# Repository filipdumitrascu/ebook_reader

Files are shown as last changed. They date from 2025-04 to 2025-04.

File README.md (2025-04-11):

# Ebook Reader (OpenBook Project)

## Contributor: Dumitrașcu Filip-Teodor 333CA

## 1. Diagrama bloc

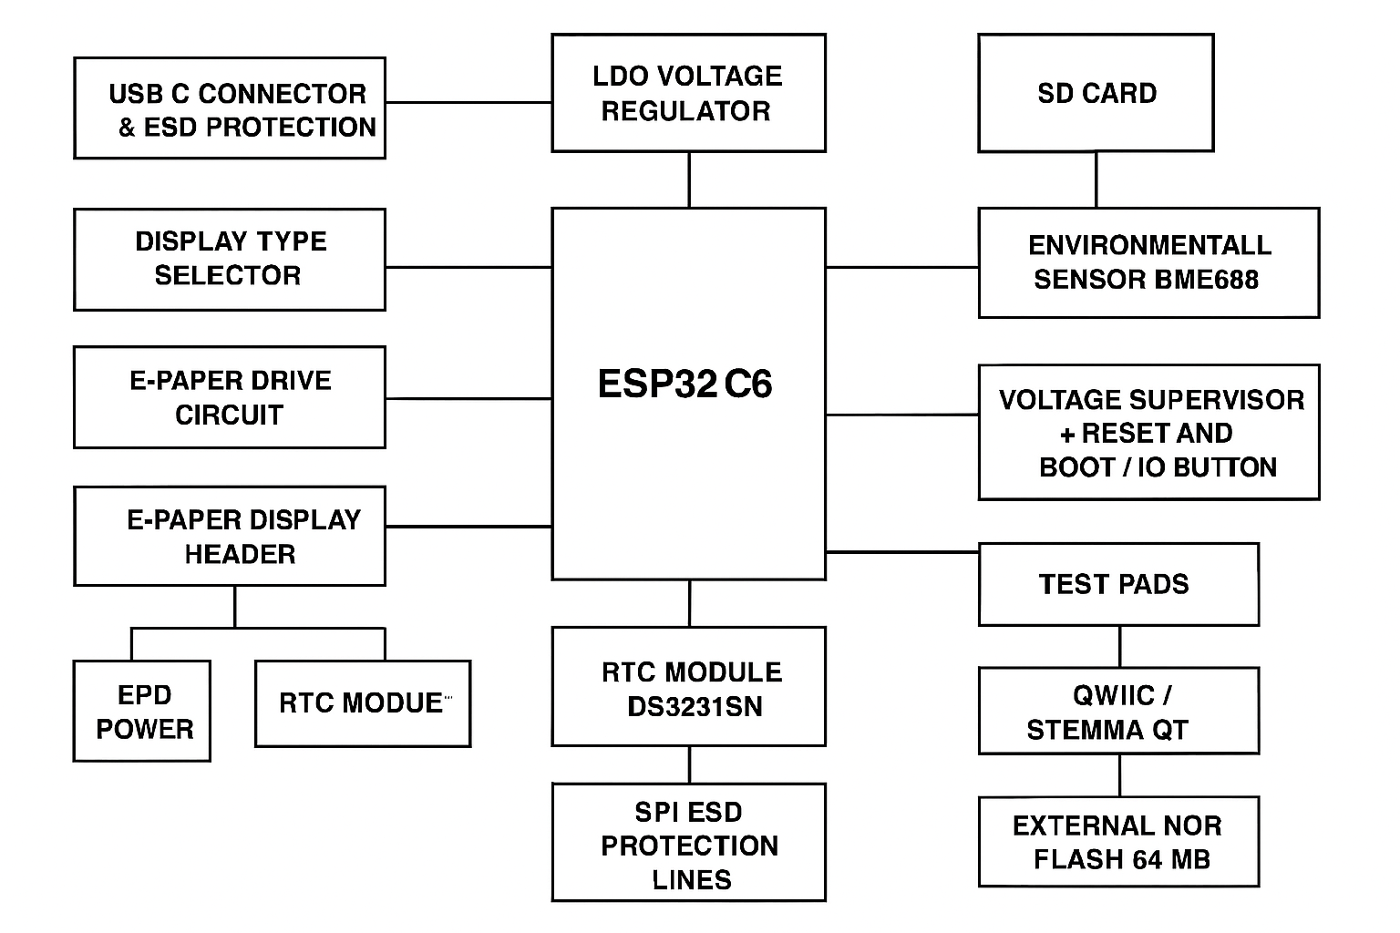
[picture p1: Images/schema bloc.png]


## 2. Bill Of Materials (BOM)

| Nume | Componenta | Link de achizitie | Datasheet |
|---|---|---|---|
| PFMF.050.1 | VARISTORCN1812 | [Component Search Engine](https://componentsearchengine.com/part-view/VE1812K401R050/KEMET) | [Datasheet](https://content.kemet.com/datasheets/KEM_V0003_VE.pdf) |
| Rezistente | RR0402 | [Component Search Engine](https://componentsearchengine.com/part-view/R0402%201%25%20100%20K%20(RC0402FR-07100KL)/YAGEO) | [Datasheet](https://content.kemet.com/datasheets/KEM_V0003_VE.pdf)
| J2 | SAMACSYS_PARTS_USB4110-GF-A | [Component Search Engine](https://componentsearchengine.com/part-view/USB4110-GF-A/GCT%20(GLOBAL%20CONNECTOR%20TECHNOLOGY)) | [Datasheet](https://gct.co/files/drawings/usb4110.pdf) |
| D1 | USBLC6-2SC6Y | [Snapeda](https://www.snapeda.com/parts/USBLC6-2SC6Y/STMicroelectronics/view-part/?ref=eda) | [Datasheet](https://www.snapeda.com/parts/USBLC6-2SC6Y/STMicroelectronics/datasheet/) |
| Condensatoare | CC0402 | [Component Search Engine](https://componentsearchengine.com/part-view/CC0402MRX5R5BB106/YAGEO) | [Datasheet](https://componentsearchengine.com/Datasheets/2/CC0402MRX5R5BB106.pdf)|
| Q1 | WROVER_SPARKFUN-DISCRETESEMI_MOSFET_PCH-DMG2305UX-7 | [Component Search Engine](https://componentsearchengine.com/part-view/DMG2305UX-7/Diodes%20Incorporated) | [Datasheet](https://www.diodes.com//assets/Datasheets/DMG2305UX.pdf) |
| D2 | WROVER_AVX---SD0805S020S1R0_AVX_SD0805S020S1R0_0_0AVX_SD0805S020S1R0_0_0 | [Mouser](https://eu.mouser.com/ProductDetail/KYOCERA-AVX/SD0805S020S1R0?qs=jCA%252BPfw4LHbpkAoSnwrdjw%3D%3D) | [Datasheet](https://eu.mouser.com/datasheet/2/40/schottky-3165252.pdf) |
| C3 | RCL_CPOL-EUCT3528 | [Snapeda](https://eu.mouser.com/ProductDetail/KYOCERA-AVX/F910J107MBAAJ6?qs=PqoDHHvF649LraCA%2FjeGXg%3D%3D) | [Datasheet](https://s3.amazonaws.com/snapeda/datasheet/TAJB475K025RNJ_AVX.pdf) |
| J4 | 112A-TAAR-R03_ATTEND | [Snapeda](https://www.snapeda.com/parts/112A-TAAR-R03/Attend/view-part/) | [Datasheet](https://www.snapeda.com/parts/112A-TAAR-R03/Attend/datasheet/) |
| U2 | C6-WROOM-1-N8 | [Snapeda](https://www.snapeda.com/parts/ESP32-C6-WROOM-1-N8/Espressif+Systems/view-part/?ref=eda) | [Datasheet](https://www.snapeda.com/parts/ESP32-C6-WROOM-1-N8/Espressif%20Systems/datasheet/) |
| MCP73831 | WROVER_SPARKFUN-IC-POWER_MCP73831 | [Mouser](https://eu.mouser.com/ProductDetail/Microchip-Technology/MCP73831T-2ACI-OT?qs=yUQqVecv4qvbBQBGbHx0Mw%3D%3D) | [Datasheet](https://eu.mouser.com/datasheet/2/268/MCP73831_Family_Data_Sheet_DS20001984H-3441711.pdf) |
| CHG_LED | ADAFRUIT_LEDCHIP-LED0603 | [Snapeda](https://www.snapeda.com/parts/KP-1608SURCK/Kingbright/view-part/?ref=search&t=LED%200603) | [Datasheet](https://www.snapeda.com/parts/KP-1608SURCK/Kingbright/datasheet/) |
| L1 | 744043680IND_4828-WE-TPC_WRE | [Mouser](https://eu.mouser.com/ProductDetail/Wurth-Elektronik/744043680?qs=PGXP4M47uW6VkZq%252BkzjrHA%3D%3D) | [Datasheet](https://www.we-online.com/components/products/datasheet/744043680.pdf) |
| D3 | MBR0530 | [Snapeda](https://www.snapeda.com/parts/MBR0530/Onsemi/view-part/?ref=eda) | [Datasheet](https://www.snapeda.com/parts/MBR0530/ON%20Semiconductor/datasheet/) |
| Q3 | SI1308EDL-T1-GE3 | [Snapeda](https://www.snapeda.com/parts/SI1308EDL-T1-GE3/Vishay+Siliconix/view-part/?ref=eda) | [Datasheet](https://www.snapeda.com/parts/SI1308EDL-T1-GE3/Vishay+Siliconix/view-part/?ref=eda) |
| SJ1 | SJ | [GrabCad](https://grabcad.com/library/solder-jumpers-1) | [Datasheet](https://www.we-online.com/components/products/datasheet/609002115121.pdf) |
| J1 | FH34SRJ-24S-0.5SH_99_ | [Component Search Engine](https://componentsearchengine.com/part-view/FH34SRJ-24S-0.5SH(99)/Hirose) | [Datasheet](https://www.hirose.com/en/product/document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) |
| Sensor2  | WROVER_BME680_BME680 | [Snapeda](https://www.snapeda.com/parts/BME680/Bosch/view-part/?welcome=home) | [Datasheet](https://www.snapeda.com/parts/BME680/Bosch%20Sensortec/datasheet/) |
| Buttons | BUTTON_CUSYOMV1 | [Snapeda](https://www.snapeda.com/parts/EVQP7L01P/Panasonic/view-part/?ref=dk&t=evqp7l01p&con_ref=None) | [Datasheet](https://s3.amazonaws.com/snapeda/datasheet/EVQP7L01P_Panasonic.pdf) |
| U4 | MAX17048G+T10 | [Snapeda](https://www.snapeda.com/parts/MAX17048G+T10/Analog+Devices/view-part/?ref=eda) | [Datasheet](https://www.snapeda.com/parts/MAX17048G+T10/Analog%20Devices/datasheet/) |
| U3 | DS3231SN# | [Snapeda](https://www.snapeda.com/parts/RV-3029-C3-TB-QA-OPT.B/Micro%20Crystal/view-part/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) | [Datasheet](https://www.snapeda.com/parts/DS3231SN%23/Analog%20Devices/datasheet/) |
| C10_SUPERCAP | CPH3225A | [Snapeda](https://www.snapeda.com/parts/CPH3225A/Seiko+Instruments/view-part/?ref=eda) | [Datasheet](https://www.snapeda.com/parts/CPH3225A/Seiko%20Instruments/datasheet/) |
| J3 | QWIIC_CONNECTORJS-1MM | [Snapeda](https://www.snapeda.com/parts/PRT-14417/SparkFun%20Electronics/view-part/?ref=search&t=QWIIC_CONNECTORJS-1MM) | [Datasheet](https://www.snapeda.com/parts/PRT-14417/SparkFun%20Electronics/view-part/?ref=search&t=QWIIC_CONNECTORJS-1MM) |
| D6,8,9,10,11,12 | PGB1010603MR | [Snapeda](https://www.snapeda.com/parts/PGB1010603MR/Littelfuse/view-part/?ref=eda) | [Datasheet](https://www.snapeda.com/parts/PGB1010603MR/Littelfuse%20Inc./datasheet/) |
| U1 | W25Q512JVEIQ | [Snapeda](https://www.snapeda.com/parts/W25Q512JVEIQ/Winbond+Electronics/view-part/?ref=eda) | [Datasheet](https://www.snapeda.com/parts/W25Q512JVEIQ/Winbond%20Electronics/datasheet/) |

## 3. Descrierea functionalitatii hardware

### Componente si interfete
- **ESP32-C6-WROOM-1-N8** este microcontrolerul principal, responsabil cu gestionarea intregului sistem, comunicarea cu senzorii si modulele externe, dar si cu managementul alimentarii.
  - Arhitectura: 32-bit RISC-V
  - Frecventa de lucru: 160 MHz
  - Conectivitate wireless: Wi-Fi 6 (2.4 GHz), Bluetooth 5.0

- **Bateria Li-Po** de 3.7V, 1800mAh asigura alimentarea sistemului in mod portabil.
- **Circuitul de incarcare** bazat pe MCP73831T gestioneaza incarcarea sigura a bateriei.
- **Regulatorul LDO** stabilizeaza tensiunea de alimentare la 3.3V pentru toate componentele.

- **Display-ul E-Ink** de 7.5 inch permite afisarea informatiilor cu un consum minim de energie.
  - Rezolutie: 800x480 pixeli
  - Interfata comunicatie: SPI

- **Modulul SD Card** permite stocarea datelor pe un card MicroSD (FAT32).
  - Interfata comunicatie: SPI

- **Memoria NOR Flash externa** ofera 64MB pentru stocare suplimentara.
  - Interfata comunicatie: SPI

- **Senzorul ambiental BME688** masoara temperatura, umiditatea, presiunea si nivelul gazelor.
  - Interfata comunicatie: I2C

- **Modulul RTC DS3231SN** mentine ora si data chiar si cand sistemul este oprit.
  - Interfata comunicatie: I2C

### Conexiuni si specificatii
- **Conectorul USB-C** permite alimentarea sistemului si transferul de date.
  - Protectie integrata ESD si dioda Schottky pentru protectie la polaritate inversa.

- **Butoane tactile** utilizate pentru interactiunea utilizatorului.

- **Interfete de comunicatie** folosite:
  - GPIO: pentru butoane si operatii I/O generale.
  - SPI: pentru SD Card, memoria NOR Flash si ecranul E-Ink.
  - I2C: pentru senzorul BME688 si modulul RTC.
  - UART: pentru debugging si comunicatie seriala.
  - Wi-Fi & Bluetooth: oferite de ESP32-C6 pentru conectivitate wireless.

## 4.Estimare Consum de Putere

| Componenta | Consum Curent (mA) | Tensiune (V) | Putere (mW) |
|---|---|---|---|
| ESP32-C6 (Wi-Fi activ) | 200 | 3.3 | 660 |
| Ecran E-Paper (Actualizare)| 40 | 3.3 | 132 |
| Senzor BME688 (Măsurare) | 3.1 | 3.3 | 10.23 |
| Modul RTC (Activ) | 0.15 | 3.3 | 0.495 |
| Card SD (Activ) | 50 | 3.3 | 165 |
| Memorie NOR Flash externa  | 25 | 3.3 | 82.5 |

### Consum Total Estimat
- Curent Total: ~318.5 mA  
- Tensiune Alimentare: 3.3 V  
- Putere Totala: 1050.72 mW

## 5. Pini utilizati pe ESP32-C6

| Pin ESP32-C6 | Funcționalitate | Componentă conectată |
|---|---|---|
| 3 | EPD_BUSY | Semnal de stare pentru EPD (E-paper display) |
| 4 | SS_SD | Chip Select pentru card SD |
| 5 | EPD_DC | Pin Data/Command pentru EPD |
| 6 | SCK | Linie de ceas SPI comună pentru EPD, SD Card și memorie externa |
| 7 | MOSI | Linie MOSI SPI (Master Out Slave In) comuna pentru EPD, SD Card si memorie externa |
| 2 | MISO | Linie MISO SPI (Master In Slave Out) comuna pentru SD Card si memorie externa |
| 10 | CS_EPD | Chip Select pentru EPD |
| 11 | CS_FLASH | Chip Select pentru memorie externă NOR Flash |
| 23 | EPD_RST | Reset pentru EPD |
| 21 | SDA | Linie de date I2C comună pentru BME688, DS3231 si monitorizare baterie |
| 22 | SCL | Linie de ceas I2C comună pentru BME688, DS3231 si monitorizare baterie |
| 18 | RTC_RST | Reset pentru modulul RTC (DS3231) |
| 1 | 32KHZ | Oscilator 32 kHz pentru RTC |
| 0 | INT_RTC | Semnal de intrerupere de la RTC |
| 9 | BOOT | Buton pentru boot/flash (input utilizator) |
| 15 | CHANGE | Buton pentru schimbare stare/functii (input utilizator) |
| EN | RESET | Buton/reset general pentru sistem |
| - | USB-C | Alimentare si programare prin USB-C (cu protecție ESD și dioda Schottky) |

## 6. Aspecte de design si probleme intampinate

- **Schematic**: Componentele au fost pozitionate conform specificatiilor arhitectului de sistem. (am pus inclusiv frame cu nume). Am acceptat 15 warninguri la verificarea erc
- **PCB 2D**: Am dat split sa obtin forma dorita in specificatii si am plasat componentele pe margini cu masurile primite pentru a ma asigura ca varianta 3d intra in carcasa si mufele sunt aliniate. Am pozitionat si componentele centrale ca in poza din specificatii. Am autorutat mai intai neturile power cu width de 0.3 mm fara trecere prin plan bottom si pe urma neturile neturile normale de 0.15 cu trecere prin plan bottom. Am pus via stitching langa modulul esp si planurile de masa atat pe top cat si pe bottom . Intradevar, sunt foarte multe viasuri puse. Poate o strategie mai buna ar fi fost sa rutez mai intai neturile normale ca sa nu fie spatiu ocupat si sa puna cat mai putine viasuri. Alta varianta ar fi fost sa rutez tot manual. (cam hardcore pentru primul proiect in fusion 360 cu acest dispozitiv un ebook reader destul de complex). Am modificat footprintul pentru piese in care intrau neturi de 0.3 mm fiind mai late decat suporta pinul piesei. In verificarea drc am 2 erori aprobate despre gauri in footprintul unei componente. (greseala a arhitectului de sistem)
- **PCB 3D**: Am downloadat step fielul si uploadat pentru fiecare componenta astfel incat sa aiba reprezentare in 3d. Test padurile sunt facute custom. Am plasat pcbul in carcasa primita de la arhitectul de sistem. Tin sa precizez ca dimensiunea de 15.30mm fata de coltul stanga sus (cu originea in coltul stanga jos) plaseaza sd cardu mai jos fata de gaura data in carcasa. Am ales sa mut gaura carcasei pentru a rezolva problema (decat sa schimb rute, replasez sd carsd si alte pushuri spre 3d)
- **Baterie, display**: Am facut o baterie si un ecram custom (am mai invatat fusion decat sa le iau step fileul de pe net) cu precizarea ca lipsesc firele de conexiune (cam mult pentru un prim proiect fusion). Dimensiuniile si componentele lor sunt luate din datasheeturile aferente.
- **Bom, PcP** Am generat de la manufacturing bom, pick and place si gerbers aferente pcbului.

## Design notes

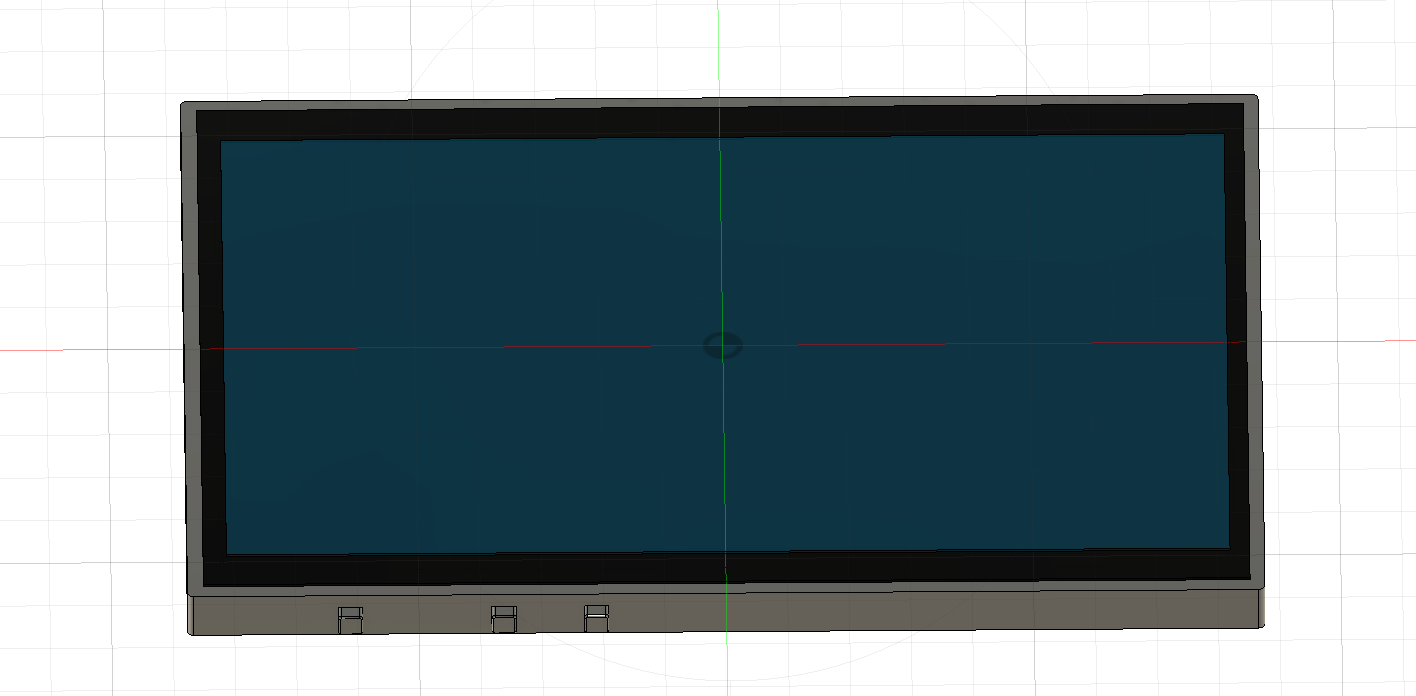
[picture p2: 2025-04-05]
Images/openbook enclosure front.png

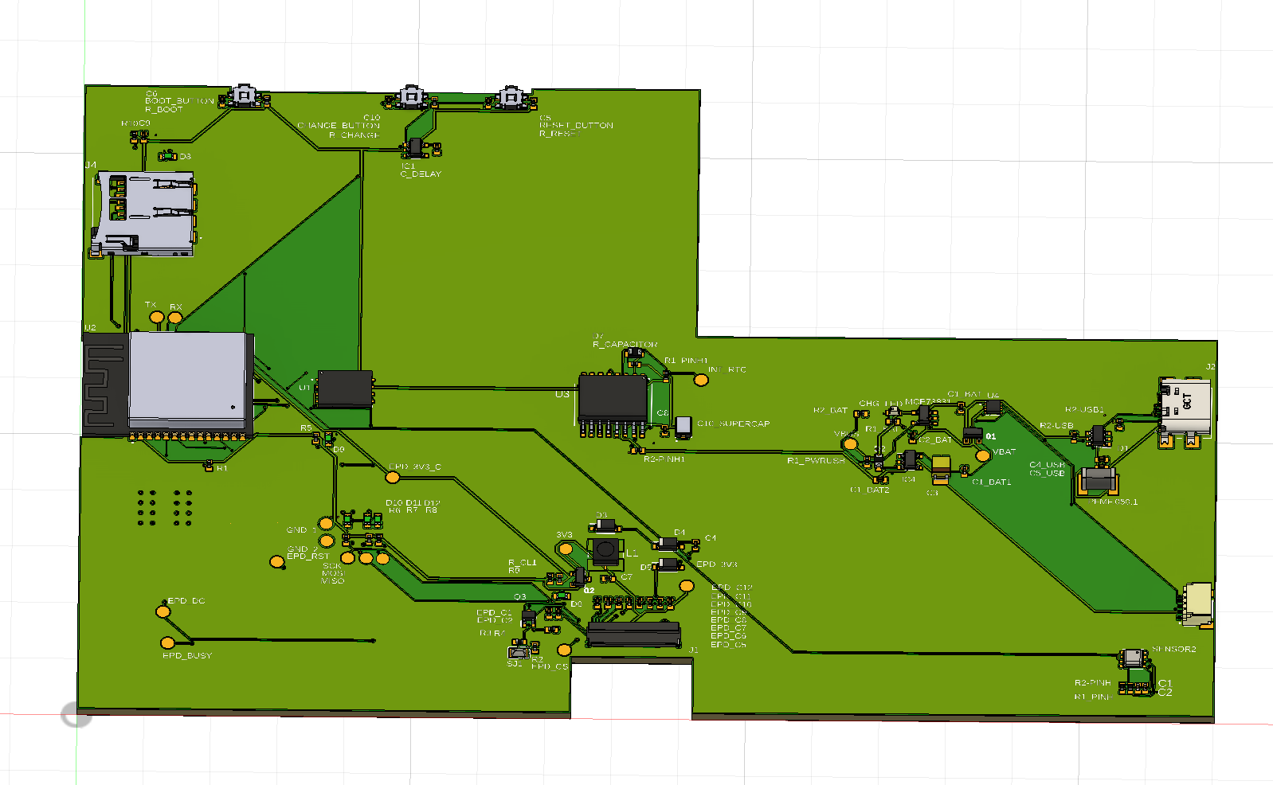
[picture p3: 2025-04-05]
Images/pcb front.png

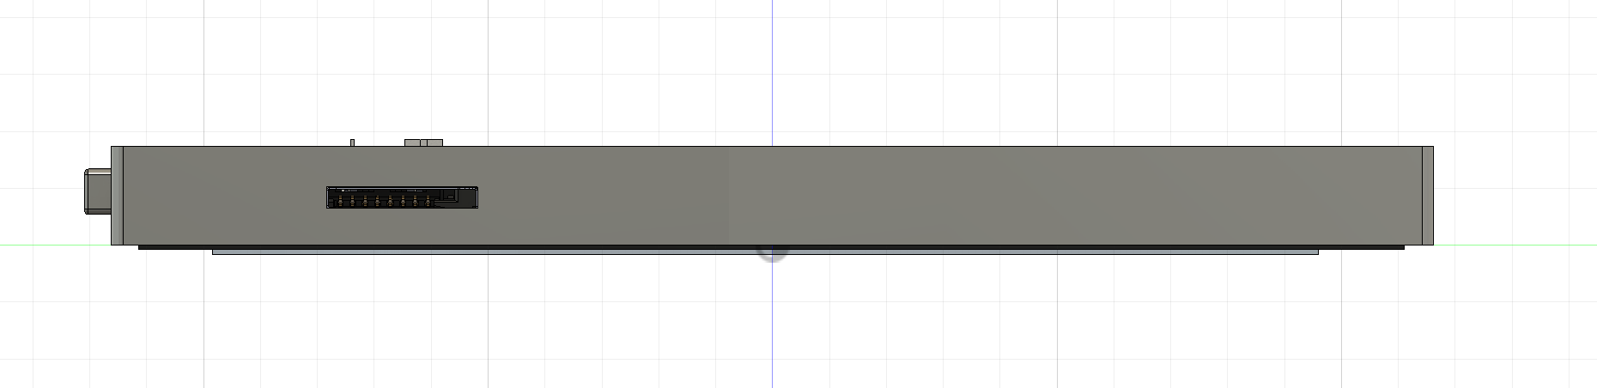
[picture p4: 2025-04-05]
Images/openbook enclosure top.png

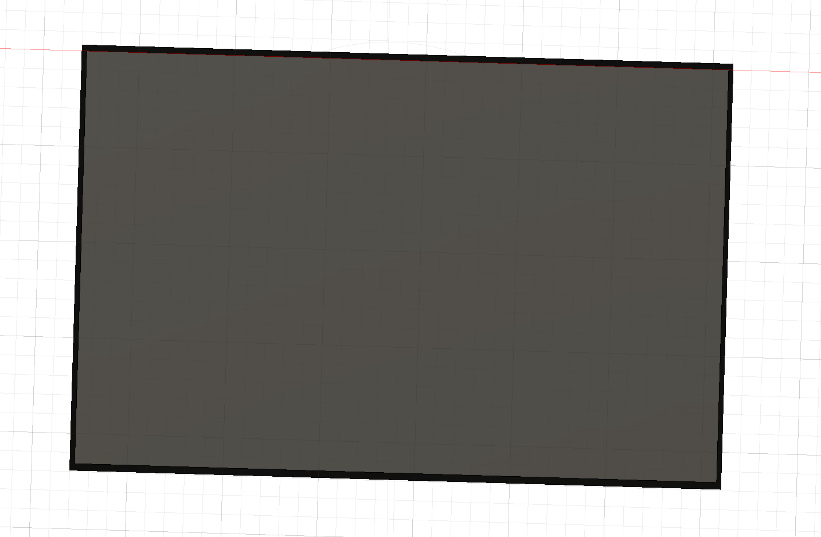
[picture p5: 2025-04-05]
Images/display back.png

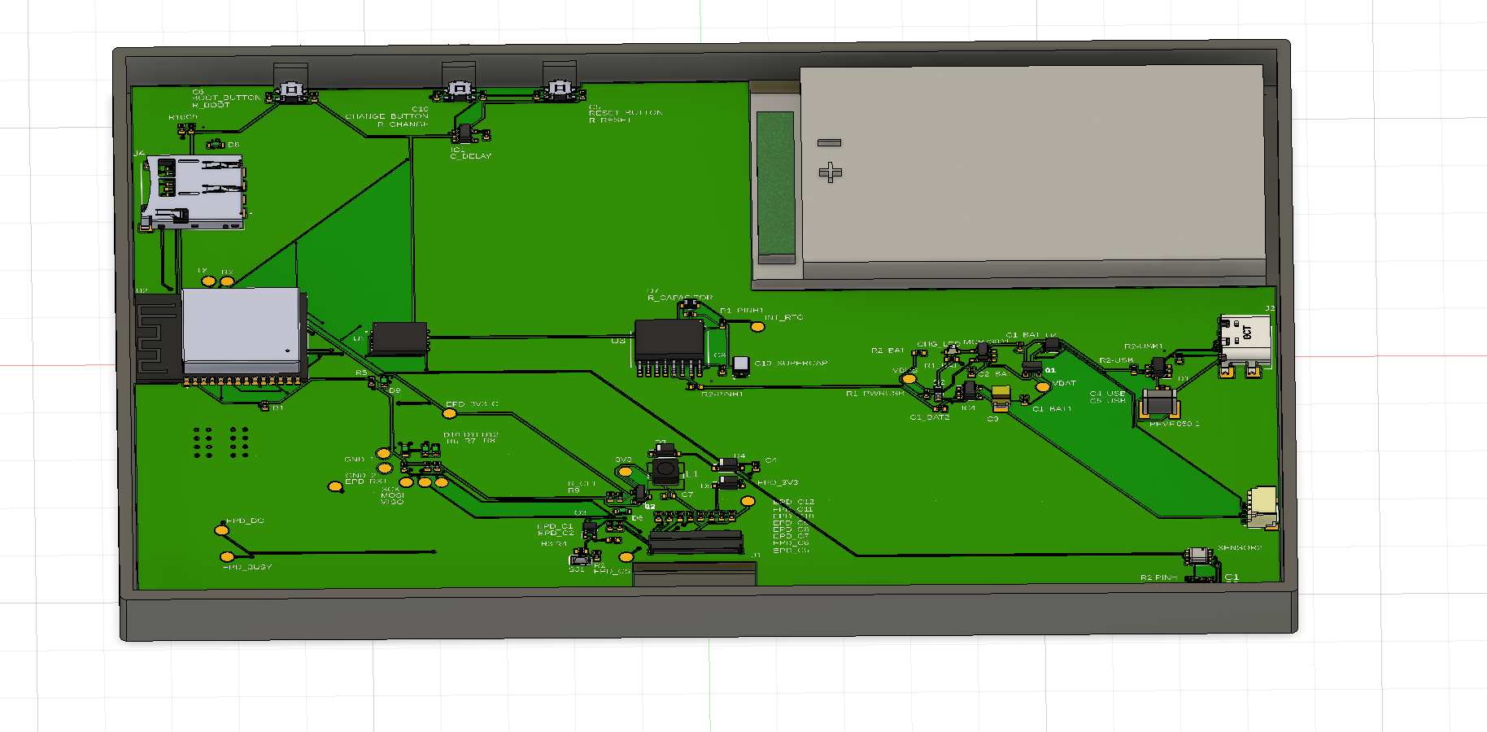
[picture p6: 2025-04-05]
Images/openbook enclosure inside.png

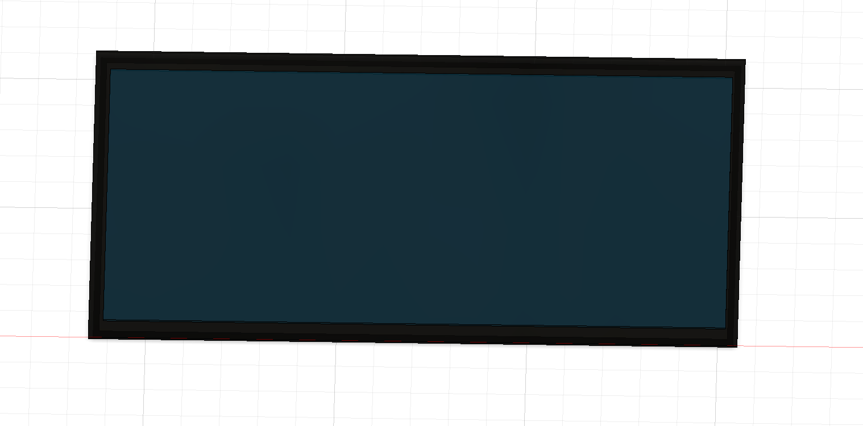
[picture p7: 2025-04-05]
Images/display front.png

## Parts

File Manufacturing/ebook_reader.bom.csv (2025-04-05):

Qty | Value | Device | Package | Parts | Description | ARROW_PART_NUMBER | ARROW_PRICE-STOCK | AVAILABILITY | CENTROID_NOT_SPECIFIED | CHECK_PRICES | COPYRIGHT | DATASHEET | DESCRIPTION | DIGIKEY_DESCRIPTION | DIGIKEY_PART_NUMBER | HEIGHT | LEAD_FREE | MANUFACTURER_NAME | MANUFACTURER_PART_NUMBER | MF | MFR_NAME | MOUSER_PART_NUMBER | MOUSER_PRICE-STOCK | MOUSER_TESTING_PART_NUMBER | MOUSER_TESTING_PRICE-STOCK | MP | MPN | PACKAGE | POPULARITY | PREFIX | PRICE | PROD_ID | PURCHASE-URL | ROHS | SNAPEDA_LINK | SPICEMODEL | SPICEPREFIX | TEMPERATURE_RANGE_HIGH | TEMPERATURE_RANGE_LOW | TP_SIGNAL_NAME | VALUE
1 |  | ADAFRUIT_LEDCHIP-LED0603 | ADAFRUIT_CHIP-LED0603 | CHG_LED | LED |  |  |  |  | https://www.snapeda.com/parts/KP-1608SURCK/Kingbright/view-part/?ref=search&t=LED%200603
1 |  | SJ | SJ | SJ1 | SMD solder JUMPER |  |  |  |  | https://grabcad.com/library/solder-jumpers-1 |  |  |  |  |  |  |  |  |  |  |  |  |  |  |  |  |  |  | 3
1 | 0.47 | ESP32_WROVER_EAGLE-LTSPICE_RR0402 | ESP32_WROVER_EAGLE-LTSPICE_R0402 | R3 | RESISTOR, European symbol |  |  |  |  | https://componentsearchengine.com/part-view/R0402%201%25%20100%20K%20(RC0402FR-07100KL)/YAGEO |  |  |  |  |  |  |  |  |  |  |  |  |  |  |  |  |  |  |  |  |  |  |  |  |  | NONE | R
1 | 10 uF | ESP32_WROVER_EAGLE-LTSPICE_CC0402 | ESP32_WROVER_EAGLE-LTSPICE_C0402 | C7 | CAPACITOR, European symbol |  |  |  |  | https://componentsearchengine.com/part-view/CC0402MRX5R5BB106/YAGEO |  |  |  |  |  |  |  |  |  |  |  |  |  |  |  |  |  |  |  |  |  |  |  |  |  | NONE | C
1 | 100 nF | ESP32_WROVER_EAGLE-LTSPICE_CC0402 | ESP32_WROVER_EAGLE-LTSPICE_C0402 | C9 | CAPACITOR, European symbol |  |  |  |  |  |  |  |  |  |  |  |  |  |  |  |  |  |  |  |  |  |  |  |  |  |  |  |  |  |  | NONE | C
1 | 100k | ESP32_WROVER_EAGLE-LTSPICE_RR0402 | ESP32_WROVER_EAGLE-LTSPICE_R0402 | R1_PWRUSB | RESISTOR, European symbol |  |  |  |  |  |  |  |  |  |  |  |  |  |  |  |  |  |  |  |  |  |  |  |  |  |  |  |  |  |  | NONE | R
7 | 100nF | ESP32_WROVER_EAGLE-LTSPICE_CC0402 | ESP32_WROVER_EAGLE-LTSPICE_C0402 | C1, C2, C4_USB, C6, C8, C10, C_DELAY | CAPACITOR, European symbol |  |  |  |  |  |  |  |  |  |  |  |  |  |  |  |  |  |  |  |  |  |  |  |  |  |  |  |  |  |  | NONE | C
1 | 100uF TANT | RCL_CPOL-EUCT3528 | RCL_CT3528 | C3 | POLARIZED CAPACITOR, European symbol |  |  |  |  | https://eu.mouser.com/ProductDetail/KYOCERA-AVX/F910J107MBAAJ6?qs=PqoDHHvF649LraCA%2FjeGXg%3D%3D |  |  |  |  |  |  |  |  |  |  |  |  |  |  |  |  |  |  | 0 |  |  |  |  |  |  |  | C
16 | 10k | ESP32_WROVER_EAGLE-LTSPICE_RR0402 | ESP32_WROVER_EAGLE-LTSPICE_R0402 | R1, R1_PINH, R1_PINH1, R2-PINH, R2-PINH1, R4, R5, R6, R7, R8, R9, R10, R_BOOT, R_CHANGE, R_CL1, R_RESET | RESISTOR, European symbol |  |  |  |  |  |  |  |  |  |  |  |  |  |  |  |  |  |  |  |  |  |  |  |  |  |  |  |  |  |  | NONE | R
1 | 112A-TAAR-R03_ATTEND | 112A-TAAR-R03_ATTEND | 112ATAARR03ATTEND | J4 | Micro SD Card Socket, Push-Push Type, Top Mount, SMT, H=1.83mm, 10u |  |  |  |  | https://www.snapeda.com/parts/112A-TAAR-R03/Attend/view-part/ |  |  | Micro SD Card Socket | Push-Push Type | Top Mount | SMT | H=1.83mm | 10u |  |  | 1.9mm |  | ATTEND | 112A-TAAR-R03 ATTEND
1 | 15 | ESP32_WROVER_EAGLE-LTSPICE_RR0402 | ESP32_WROVER_EAGLE-LTSPICE_R0402 | R_CAPACITOR | RESISTOR, European symbol |  |  |  |  |  |  |  |  |  |  |  |  |  |  |  |  |  |  |  |  |  |  |  |  |  |  |  |  |  |  | NONE | R
1 | 1uF | ESP32_WROVER_EAGLE-LTSPICE_CC0402 | ESP32_WROVER_EAGLE-LTSPICE_C0402 | C5 | CAPACITOR, European symbol |  |  |  |  |  |  |  |  |  |  |  |  |  |  |  |  |  |  |  |  |  |  |  |  |  |  |  |  |  |  | NONE | C
10 | 1uF/50V | ESP32_WROVER_EAGLE-LTSPICE_CC0402 | ESP32_WROVER_EAGLE-LTSPICE_C0402 | EPD_C1, EPD_C2, EPD_C5, EPD_C6, EPD_C7\, EPD_C8, EPD_C9, EPD_C10, EPD_C11, EPD_C12 | CAPACITOR, European symbol |  |  |  |  |  |  |  |  |  |  |  |  |  |  |  |  |  |  |  |  |  |  |  |  |  |  |  |  |  |  | NONE | C
1 | 2.2 | ESP32_WROVER_EAGLE-LTSPICE_RR0402 | ESP32_WROVER_EAGLE-LTSPICE_R0402 | R2 | RESISTOR, European symbol |  |  |  |  |  |  |  |  |  |  |  |  |  |  |  |  |  |  |  |  |  |  |  |  |  |  |  |  |  |  | NONE | R
1 | 200 | ESP32_WROVER_EAGLE-LTSPICE_RR0402 | ESP32_WROVER_EAGLE-LTSPICE_R0402 | R1_BAT | RESISTOR, European symbol |  |  |  |  |  |  |  |  |  |  |  |  |  |  |  |  |  |  |  |  |  |  |  |  |  |  |  |  |  |  | NONE | R
2 | 20V/4.2A/52mO/1.4W | ESP32_WROVER_SPARKFUN-DISCRETESEMI_MOSFET_PCH-DMG2305UX-7 | ESP32_WROVER_SPARKFUN-DISCRETESEMI_SOT23-3 | Q1, Q2 | P-channel MOSFETs |  |  |  |  | https://componentsearchengine.com/part-view/DMG2305UX-7/Diodes%20Incorporated |  |  |  |  |  |  |  |  |  |  |  |  |  |  |  |  |  |  |  |  |  | TRAN-14388 |  |  |  |  |  |  |  |  | 20V/4.2A/52mO/1.4W
1 | 2k | ESP32_WROVER_EAGLE-LTSPICE_RR0402 | ESP32_WROVER_EAGLE-LTSPICE_R0402 | R2_BAT | RESISTOR, European symbol |  |  |  |  |  |  |  |  |  |  |  |  |  |  |  |  |  |  |  |  |  |  |  |  |  |  |  |  |  |  | NONE | R
4 | 4.7 uF | ESP32_WROVER_EAGLE-LTSPICE_CC0402 | ESP32_WROVER_EAGLE-LTSPICE_C0402 | C1_BAT, C1_BAT1, C1_BAT2, C2_BAT | CAPACITOR, European symbol |  |  |  |  |  |  |  |  |  |  |  |  |  |  |  |  |  |  |  |  |  |  |  |  |  |  |  |  |  |  | NONE | C
1 | 4.7uF | ESP32_WROVER_EAGLE-LTSPICE_CC0402 | ESP32_WROVER_EAGLE-LTSPICE_C0402 | C5_USB | CAPACITOR, European symbol |  |  |  |  |  |  |  |  |  |  |  |  |  |  |  |  |  |  |  |  |  |  |  |  |  |  |  |  |  |  | NONE | C
1 | 4.7uF/25V | ESP32_WROVER_EAGLE-LTSPICE_CC0402 | ESP32_WROVER_EAGLE-LTSPICE_C0402 | C4 | CAPACITOR, European symbol |  |  |  |  |  |  |  |  |  |  |  |  |  |  |  |  |  |  |  |  |  |  |  |  |  |  |  |  |  |  | NONE | C
2 | 5k1 | ESP32_WROVER_EAGLE-LTSPICE_RR0402 | ESP32_WROVER_EAGLE-LTSPICE_R0402 | R2-USB, R2-USB1 | RESISTOR, European symbol |  |  |  |  |  |  |  |  |  |  |  |  |  |  |  |  |  |  |  |  |  |  |  |  |  |  |  |  |  |  | NONE | R
1 | 68uH | 744043680IND_4828-WE-TPC_WRE | IND_4828-WE-TPC_WRE | L1 |  |  |  |  |  | https://eu.mouser.com/ProductDetail/Wurth-Elektronik/744043680?qs=PGXP4M47uW6VkZq%252BkzjrHA%3D%3D | Copyright (C) 2024 Ultra Librarian. All rights reserved. |  |  |  |  |  |  |  | 744043680 |  | Wurth Electronics
1 | BD5229G-TR | BD5229G-TR | SOT95P280X125-5N | IC1 | Voltage Detector with Adjustable Delay Time: CMOS processes are utilized to develop high precision, low current consumption CMOS reset ICs that allow arbitrary setting of the delay time. The extensive lineup includes both Nch Open Drain and CMOS output types in a wide range of detection voltages (from 2.3V to 6.0V, in 0.1V steps), enabling selection of the ideal solution based on customer requirements. In addition, the entire series is of course both lead-free and RoHS-compliant. |  |  |  |  | https://componentsearchengine.com/part-view/BD5229G-TR/ROHM%20Semiconductor |  |  | Voltage Detector with Adjustable Delay Time: CMOS processes are utilized to develop high precision | low current consumption CMOS reset ICs that allow arbitrary setting of the delay time. The extensive lineup includes both Nch Open Drain and CMOS output types in a wide range of detection voltages (from 2.3V to 6.0V | in 0.1V steps) | enabling selection of the ideal solution based on customer requirements. In addition | the entire series is of course both lead-free and RoHS-compliant. |  |  | 1.25mm |  | ROHM Semiconductor | BD5229G-TR |  |  | 755-BD5229G-TR | https://www.mouser.co.uk/ProductDetail/ROHM-Semiconductor/BD5229G-TR?qs=4kLU8WoGk0vvnhrrYwdszw%3D%3D
3 | BUTTON_CUSYOMV1 | BUTTON_CUSYOMV1 | MYBUTTON | BOOT_BUTTON, CHANGE_BUTTON, RESET_BUTTON |  |  |  |  |  | https://www.snapeda.com/parts/EVQP7L01P/Panasonic/view-part/?ref=dk&t=evqp7l01p&con_ref=None
1 | CPH3225A | CPH3225A | CAPCP3225X100N | C10_SUPERCAP | Cap 0.011F 3.3V 1210 Flat Check availability |  |  | Not in stock |  | https://www.snapeda.com/parts/CPH3225A/Seiko+Instruments/view-part/?ref=eda |  |  | 11 mF (EDLC) Supercapacitor 3.3 V 1210 (3225 Metric) - - |  |  |  |  |  |  | Seiko Instruments |  |  |  |  |  | CPH3225A |  | 1210 Seiko |  |  | None |  | https://www.snapeda.com/api/url_track_click_mouser/?unipart_id=562593&manufacturer=Seiko Instruments&part_name=CPH3225A&search_term=None |  | https://www.snapeda.com/parts/CPH3225A/Seiko+Instruments/view-part/?ref=snap
1 | DS3231SN# | DS3231SN# | SOIC127P1032X265-16N | U3 | Real Time Clock Serial 16-Pin SOIC W T/R Check availability |  |  | In Stock |  | https://www.snapeda.com/parts/DS3231SN%23/Analog+Devices/view-part/?ref=eda |  |  | Extremely Accurate I²C-Integrated RTC/TCXO/Crystal |  |  |  |  |  |  | Analog Devices |  |  |  |  |  | DS3231SN# |  | SOIC-16 Maxim |  |  | None |  | https://www.snapeda.com/api/url_track_click_mouser/?unipart_id=99048&manufacturer=Analog Devices&part_name=DS3231SN#&search_term=None |  | https://www.snapeda.com/parts/DS3231SN%23/Analog+Devices/view-part/?ref=snap
1 | ESP32-C6-WROOM-1-N8 | ESP32-C6-WROOM-1-N8 | XCVR_ESP32-C6-WROOM-1-N8 | U2 | Check availability |  |  | In Stock |  | https://www.snapeda.com/parts/ESP32-C6-WROOM-1-N8/Espressif+Systems/view-part/?ref=eda |  |  | Multiprotocol Modules ESP32-C6 module | Wi-Fi 6 in 2.4 GHz band | Bluetooth 5 | Zigbee 3.0 and Thread. ESP34-WROOM Compatible - ENGINEERING SAMPLE |  |  |  |  |  |  | Espressif Systems |  |  |  |  |  | ESP32-C6-WROOM-1-N8 |  | None |  |  | None |  |  |  | https://www.snapeda.com/parts/ESP32-C6-WROOM-1-N8/Espressif+Systems/view-part/?ref=snap
1 | ESP32C6_VARISTORCN1812 | ESP32C6_VARISTORCN1812 | ESP32C6_VARISTOR_CT/CN1812 | PFMF.050.1 | VARISTOR |  |  |  |  | https://componentsearchengine.com/part-view/VE1812K401R050/KEMET |  |  |  |  |  |  |  |  |  |  |  |  |  |  |  |  |  |  | 0
2 | ESP32_WROVER_AVX---SD0805S020S1R0_AVX_SD0805S020S1R0_0_0AVX_SD0805S020S1R0_0_0 | ESP32_WROVER_AVX---SD0805S020S1R0_AVX_SD0805S020S1R0_0_0AVX_SD0805S020S1R0_0_0 | ESP32_WROVER_AVX---SD0805S020S1R0_AVX_SD0805S020S1R0_0 | D2, D7 | Schottky Barrier Rectifier Diode |  |  |  | No | https://eu.mouser.com/ProductDetail/KYOCERA-AVX/SD0805S020S1R0?qs=jCA%252BPfw4LHbpkAoSnwrdjw%3D%3D |  | http://datasheets.avx.com/schottky.pdf |  | DIODE SCHOTTKY 20V 1A 0805 | 478-7800-1-ND |  | yes |  |  | AVX |  | 581-SD0805S020S1R0 |  |  |  |  |  | 0805 (2012 metric) |  | D |  |  |  | yes |  |  |  | +125°C | -55°C
1 | ESP32_WROVER_BME680_BME680 | ESP32_WROVER_BME680_BME680 | ESP32_WROVER_BME680_PSON80P300X300X100-8N | SENSOR2 | Integrated Environmental Unit |  |  | Unavailable |  | https://www.snapeda.com/parts/BME680/Bosch/view-part/?welcome=home |  |  | Integrated Environmental Unit |  |  |  |  |  |  | Bosch Sensortec |  |  |  |  |  | BME680 |  | LGA-8 Bosch Tools |  |  | None
1 | ESP32_WROVER_SPARKFUN-IC-POWER_MCP73831 | ESP32_WROVER_SPARKFUN-IC-POWER_MCP73831 | ESP32_WROVER_SPARKFUN-IC-POWER_SOT23-5 | MCP73831 | MCP73831T Li-Ion, Li-Pol Controller |  |  |  |  | https://eu.mouser.com/ProductDetail/Microchip-Technology/MCP73831T-2ACI-OT?qs=yUQqVecv4qvbBQBGbHx0Mw%3D%3D |  |  |  |  |  |  |  |  |  |  |  |  |  |  |  |  |  |  |  |  |  | IC-09995
1 | FH34SRJ-24S-0.5SH_99_ | FH34SRJ-24S-0.5SH_99_ | FH34SRJ24S05SH99 | J1 | (0.50mm) Surface Mount, Right Angle |  |  |  |  | https://componentsearchengine.com/part-view/FH34SRJ-24S-0.5SH(99)/Hirose |  |  | 24 Position FFC | FPC Connector Contacts | (0.50mm) Surface Mount | Right Angle |  |  | 1.1mm |  | Hirose | FH34SRJ-24S-0.5SH(99) |  |  | 798-FH34SRJ24S05SH99 | https://www.mouser.co.uk/ProductDetail/Hirose-Connector/FH34SRJ-24S-0.5SH99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
1 | MAX17048G+T10 | MAX17048G+T10 | SON50P200X200X80-9N | U4 | Check availability |  |  | In Stock |  | https://www.snapeda.com/parts/MAX17048G+T10/Analog+Devices/view-part/?ref=eda |  |  | 3µA 1-Cell/2-Cell Fuel Gauge with ModelGauge |  |  |  |  |  |  | Analog Devices |  |  |  |  |  | MAX17048G+T10 |  | TDFN-8 Maxim |  |  | None |  | https://www.snapeda.com/api/url_track_click_mouser/?unipart_id=329239&manufacturer=Analog Devices&part_name=MAX17048G+T10&search_term=None |  | https://www.snapeda.com/parts/MAX17048G+T10/Analog+Devices/view-part/?ref=snap
3 | MBR0530 | MBR0530 | SOD3716X135N | D3, D4, D5 | ON SEMICONDUCTOR - MBR0530 - DIODE, SCHOTTKY, 0.5A, 30V, SOD-123 |  |  | In Stock |  | https://www.snapeda.com/parts/MBR0530/Onsemi/view-part/?ref=eda |  |  | Diode Schottky 30 V 500mA Surface Mount SOD-123 |  |  |  |  |  |  | ON Semiconductor |  |  |  |  |  | MBR0530 |  | SOD-123-2 ON Semiconductor |  |  | None |  | https://www.snapeda.com/api/url_track_click_mouser/?unipart_id=179458&manufacturer=ON Semiconductor&part_name=MBR0530&search_term=None |  | https://www.snapeda.com/parts/MBR0530/Onsemi/view-part/?ref=snap
6 | PGB1010603MR | PGB1010603MR | DIOC1608X36N | D6, D8, D9, D10, D11, D12 | Check availability |  |  | In Stock |  | https://www.snapeda.com/parts/PGB1010603MR/Littelfuse/view-part/?ref=eda |  |  | 150V (Typ) Clamp - Ipp Tvs Diode Surface Mount 0603 (1608 Metric) |  |  |  |  |  |  | Littelfuse Inc. |  |  |  |  |  | PGB1010603MR |  | 0603 Littelfuse Inc. |  |  | None |  | https://www.snapeda.com/api/url_track_click_mouser/?unipart_id=5659453&manufacturer=Littelfuse Inc.&part_name=PGB1010603MR&search_term=None |  | https://www.snapeda.com/parts/PGB1010603MR/Littelfuse/view-part/?ref=snap
1 | QWIIC_RIGHT_ANGLE | QWIIC_CONNECTORJS-1MM | JST04_1MM_RA | J3 | SparkFun I2C Standard Qwiic Connector |  |  |  |  | https://www.snapeda.com/parts/PRT-14417/SparkFun%20Electronics/view-part/?t=QWIIC_CONNECTORJS-1MM |  |  |  |  |  |  |  |  |  |  |  |  |  |  |  |  |  |  |  |  |  | CONN-13694 |  |  |  |  |  |  |  |  | QWIIC_RIGHT_ANGLE
1 | SAMACSYS_PARTS_USB4110-GF-A | SAMACSYS_PARTS_USB4110-GF-A | SAMACSYS_PARTS_USB4110GFA | J2 | CONN USB 2.0 TYPE-C R/A SMT |  |  |  |  | https://componentsearchengine.com/part-view/USB4110-GF-A/GCT%20(GLOBAL%20CONNECTOR%20TECHNOLOGY) |  |  | CONN USB 2.0 TYPE-C R/A SMT |  |  | 3.26mm |  | GCT (GLOBAL CONNECTOR TECHNOLOGY) | USB4110-GF-A |  |  | 640-USB4110-GF-A | https://www.mouser.co.uk/ProductDetail/GCT/USB4110-GF-A?qs=KUoIvG%2F9IlYiZvIXQjyJeA%3D%3D
1 | SI1308EDL-T1-GE3 | SI1308EDL-T1-GE3 | SOT65P210X110-3N | Q3 | MOSFET N-Ch 30V 1.5A TrenchFET SC70 Vishay Si1308EDL-T1-GE3 N-channel MOSFET Transistor, 1.5 A, 30 V, 3-Pin SC-70 |  |  | In Stock |  | https://www.snapeda.com/parts/SI1308EDL-T1-GE3/Vishay+Siliconix/view-part/?ref=eda |  |  | Si1308EDL-T1-GE3 N-channel MOSFET Transistor | 1.5 A | 30 V | 3-Pin SC-70 | Siliconix / Vishay SI1308EDL-T1-GE3 |  |  |  |  |  |  | Vishay Siliconix |  |  |  |  |  | SI1308EDL-T1-GE3 |  | SOT-323 Vishay Semiconductor |  |  | None |  | https://www.snapeda.com/api/url_track_click_mouser/?unipart_id=274603&manufacturer=Vishay Siliconix&part_name=SI1308EDL-T1-GE3&search_term=None |  | https://www.snapeda.com/parts/SI1308EDL-T1-GE3/Vishay+Siliconix/view-part/?ref=snap
17 | TPTP20R | TPTP20R | TP20R | 3V3, EPD_3V3, EPD_3V3_C, EPD_BUSY, EPD_CS, EPD_DC, EPD_RST, GND_1, GND_2, INT_RTC, MISO, MOSI, RX, SCK, TX, VBAT, VBUS | Test pad |  |  |  |  |  |  |  |  |  |  |  |  |  |  |  |  |  |  |  |  |  |  |  | 2
1 | USBLC6-2SC6Y | USBLC6-2SC6Y | SOT95P280X145-6N | D1 | Low Cap. ESD Protection Auto SOT-23-6 STMicroelectronics USBLC6-2SC6Y, Dual Uni-Directional TVS Diode Array, 6-Pin SOT-23 |  |  | In Stock |  | https://www.snapeda.com/parts/USBLC6-2SC6Y/STMicroelectronics/view-part/?ref=eda |  |  | 17V Clamp 5A (8/20µs) Ipp Tvs Diode Surface Mount SOT-23-6 |  |  |  |  |  |  | STMicroelectronics |  |  |  |  |  | USBLC6-2SC6Y |  | SOT-23-6 STMicroelectronics |  |  | None |  |  |  | https://www.snapeda.com/parts/USBLC6-2SC6Y/STMicroelectronics/view-part/?ref=snap
1 | W25Q512JVEIQ | W25Q512JVEIQ | SON127P600X800X80-9N | U1 | Check availability |  |  | In Stock |  | https://www.snapeda.com/parts/W25Q512JVEIQ/Winbond+Electronics/view-part/?ref=eda |  |  | FLASH - NOR Memory IC 512Mb (64M x 8) SPI - Quad I/O 133 MHz 8-WSON (8x6) |  |  |  |  |  |  | Winbond Electronics |  |  |  |  |  | W25Q512JVEIQ |  | Package |  |  | None |  |  |  | https://www.snapeda.com/parts/W25Q512JVEIQ/Winbond+Electronics/view-part/?ref=snap
1 | XC6220A331MR-G | XC6220A331MR-G | SOT95P280X120-5N | IC4 | LDO Voltage Regulators |  |  |  |  | https://componentsearchengine.com/part-view/XC6220A331MR-G/Torex |  |  | LDO Voltage Regulators |  |  | 1.2mm |  | Torex | XC6220A331MR-G |  |  | 865-XC6220A331MR-G | https://www.mouser.co.uk/ProductDetail/Torex-Semiconductor/XC6220A331MR-G?qs=AsjdqWjXhJ8ZSWznL1J0gg%3D%3D

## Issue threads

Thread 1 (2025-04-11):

(README) Power Consumption

melisa204, 2025-04-11:
Currently, the project does not specify the power consumption of its components. It would be very useful to add a table listing each component with its current draw, voltage, and power.

filipdumitrascu, 2025-04-14:
Added!

Closed 2025-04-14.

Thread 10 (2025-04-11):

(MECHANICAL) PCB Thickness

melisa204, 2025-04-11:
PCB thickness not 1mm, as specified

filipdumitrascu, 2025-04-14:
Fixed! But 1.6 mm worked as well

Closed 2025-04-14.

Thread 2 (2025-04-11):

(README) ESP32-C6 pins

melisa204, 2025-04-11:
The current documentation lacks detailed information on the ESP32-C6 pins in use. Each pin should be thoroughly described, including its specific purpose and the interface provided to each component.

filipdumitrascu, 2025-04-14:
Added pin information.

Closed 2025-04-14.

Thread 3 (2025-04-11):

(SCHEMATIC) Poor Spacing & Crowded

melisa204, 2025-04-11:
The schematic layout is very crowded, with components and traces overlapping the diagram's boundaries. This overlap makes it difficult to follow the circuit's structure. A more spacious and organized layout would improve readability and usability.

Closed 2025-04-14.

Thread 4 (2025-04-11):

(PCB) Missing External Dimension Details

melisa204, 2025-04-11:
The PCB design does not display the external dimensions—specifically, the distances that define the board's outline are missing. Without these measurements, it's challenging to understand the board's overall size and shape.

filipdumitrascu, 2025-04-14:
There are now external dimensions

Closed 2025-04-14.

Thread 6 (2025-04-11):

(MECHANICAL) Missing File

melisa204, 2025-04-11:
Exploded view (.step) is missing, although it's great that you've attached a video and PDF instead.

filipdumitrascu, 2025-04-14:
Added although it makes no sense, the video and pdf are a better exploded view option.

Closed 2025-04-14.

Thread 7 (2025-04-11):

(SCHEMATIC) Missing name

melisa204, 2025-04-11:
Your schematic:

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

is missing DMG2305UX-7; here's the reference:

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

filipdumitrascu, 2025-04-14:
FIxed but...

Closed 2025-04-14.

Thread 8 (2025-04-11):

(SCHEMATIC) Reversed component

melisa204, 2025-04-11:
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

In this instance, the component appears reversed compared to the reference design:

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

While the orientation might still work correctly, I wanted to note it as a cautionary warning.

Closed 2025-04-14.

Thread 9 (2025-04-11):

(SCHEMATIC) Additional name / value annotation

melisa204, 2025-04-11:
In your schematic, there’s an additional label or value that doesn’t appear in the reference design (SAMACSYS_PARTS_USB4110-GF-A).
I don't think there's an issue, I just wanted to note it as a cautionary warning.

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

filipdumitrascu, 2025-04-14:
Won't fix. This issue does not affect functionality.

Closed 2025-04-14.

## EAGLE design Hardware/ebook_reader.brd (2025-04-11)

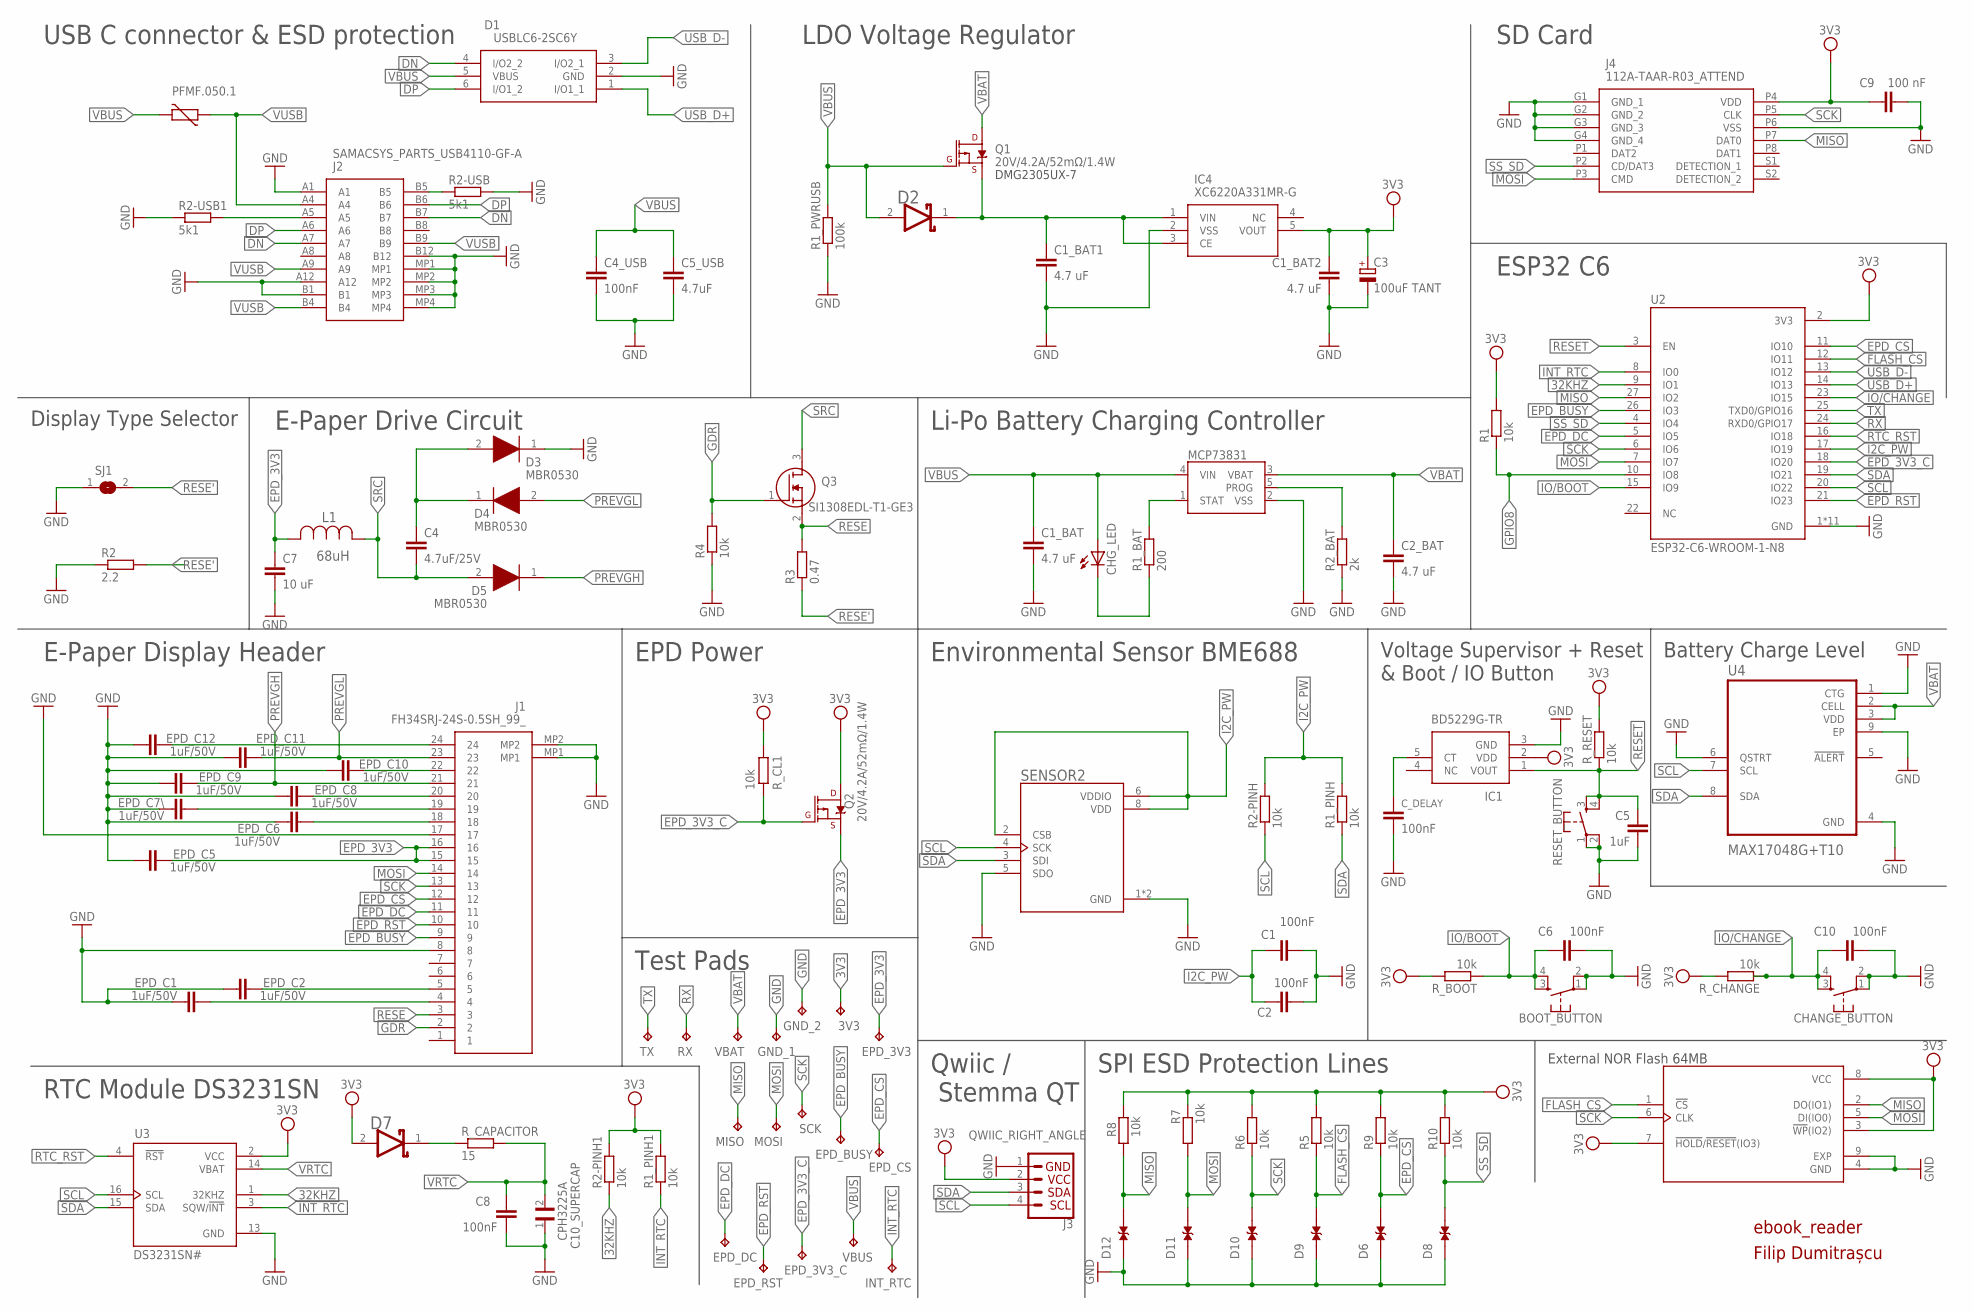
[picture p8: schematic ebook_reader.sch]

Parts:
3V3: TPTP20R; TP20R
BOOT_BUTTON: BUTTON_CUSYOMV1; MYBUTTON
C1, C2, C4_USB, C6, C8, C10: 100nF; ESP32_WROVER_EAGLE-LTSPICE_C0402
C1_BAT, C1_BAT1, C1_BAT2, C2_BAT: 4.7 uF; ESP32_WROVER_EAGLE-LTSPICE_C0402
C3: 100uF TANT; RCL_CT3528
C4: 4.7uF/25V; ESP32_WROVER_EAGLE-LTSPICE_C0402
C5: 1uF; ESP32_WROVER_EAGLE-LTSPICE_C0402
C5_USB: 4.7uF; ESP32_WROVER_EAGLE-LTSPICE_C0402
C7: 10 uF; ESP32_WROVER_EAGLE-LTSPICE_C0402
C9: 100 nF; ESP32_WROVER_EAGLE-LTSPICE_C0402
C10_SUPERCAP: CPH3225A; CAPCP3225X100N
CHANGE_BUTTON: BUTTON_CUSYOMV1; MYBUTTON
CHG_LED: ADAFRUIT_LEDCHIP-LED0603; ADAFRUIT_CHIP-LED0603
C_DELAY: 100nF; ESP32_WROVER_EAGLE-LTSPICE_C0402
D1: USBLC6-2SC6Y; SOT95P280X145-6N
D2, D7: ESP32_WROVER_AVX---SD0805S020S1R0_AVX_SD0805S020S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; ESP32_WROVER_AVX---SD0805S020S1R0_AVX_SD0805S020S1R0_0
D3, D4, D5: MBR0530; SOD3716X135N
D6, D8, D9, D10, D11, D12: PGB1010603MR; DIOC1608X36N
EPD_3V3, EPD_3V3_C: TPTP20R; TP20R
EPD_BUSY: TPTP20R; TP20R
EPD_C1, EPD_C2, EPD_C5, EPD_C6, EPD_C7\, EPD_C8, EPD_C9, EPD_C10, EPD_C11, EPD_C12: 1uF/50V; ESP32_WROVER_EAGLE-LTSPICE_C0402
EPD_CS: TPTP20R; TP20R
EPD_DC: TPTP20R; TP20R
EPD_RST: TPTP20R; TP20R
GND_1, GND_2: TPTP20R; TP20R
IC1: BD5229G-TR; SOT95P280X125-5N
IC4: XC6220A331MR-G; SOT95P280X120-5N
INT_RTC: TPTP20R; TP20R
J1: FH34SRJ-24S-0.5SH_99_; FH34SRJ24S05SH99
J2: SAMACSYS_PARTS_USB4110-GF-A; SAMACSYS_PARTS_USB4110GFA
J3: QWIIC_RIGHT_ANGLE; JST04_1MM_RA
J4: 112A-TAAR-R03_ATTEND; 112ATAARR03ATTEND
L1: 68uH; IND_4828-WE-TPC_WRE
MCP73831: ESP32_WROVER_SPARKFUN-IC-POWER_MCP73831; ESP32_WROVER_SPARKFUN-IC-POWER_SOT23-5
MISO: TPTP20R; TP20R
MOSI: TPTP20R; TP20R
PFMF.050.1: ESP32C6_VARISTORCN1812; ESP32C6_VARISTOR_CT/CN1812
Q1, Q2: 20V/4.2A/52mΩ/1.4W; ESP32_WROVER_SPARKFUN-DISCRETESEMI_SOT23-3
Q3: SI1308EDL-T1-GE3; SOT65P210X110-3N
R1, R1_PINH, R1_PINH1, R2-PINH, R2-PINH1, R4, R5, R6, R7, R8, R9, R10: 10k; ESP32_WROVER_EAGLE-LTSPICE_R0402
R1_BAT: 200; ESP32_WROVER_EAGLE-LTSPICE_R0402
R1_PWRUSB: 100k; ESP32_WROVER_EAGLE-LTSPICE_R0402
R2: 2.2; ESP32_WROVER_EAGLE-LTSPICE_R0402
R2-USB, R2-USB1: 5k1; ESP32_WROVER_EAGLE-LTSPICE_R0402
R2_BAT: 2k; ESP32_WROVER_EAGLE-LTSPICE_R0402
R3: 0.47; ESP32_WROVER_EAGLE-LTSPICE_R0402
RESET_BUTTON: BUTTON_CUSYOMV1; MYBUTTON
RX: TPTP20R; TP20R
R_BOOT: 10k; ESP32_WROVER_EAGLE-LTSPICE_R0402
R_CAPACITOR: 15; ESP32_WROVER_EAGLE-LTSPICE_R0402
R_CHANGE: 10k; ESP32_WROVER_EAGLE-LTSPICE_R0402
R_CL1: 10k; ESP32_WROVER_EAGLE-LTSPICE_R0402
R_RESET: 10k; ESP32_WROVER_EAGLE-LTSPICE_R0402
SCK: TPTP20R; TP20R
SENSOR2: ESP32_WROVER_BME680_BME680; ESP32_WROVER_BME680_PSON80P300X300X100-8N
SJ1: SJ
TX: TPTP20R; TP20R
U1: W25Q512JVEIQ; SON127P600X800X80-9N
U2: ESP32-C6-WROOM-1-N8; XCVR_ESP32-C6-WROOM-1-N8
U3: DS3231SN#; SOIC127P1032X265-16N
U4: MAX17048G+T10; SON50P200X200X80-9N
VBAT: TPTP20R; TP20R
VBUS: TPTP20R; TP20R

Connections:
3V3: 3V3.TP, C1_BAT2.1, C3.+, C9.1, D7.2 (ANODE), IC1.2 (VDD), IC4.5 (VOUT), J3.2, J4.P4 (VDD), Q2.3 (D), R1.2, R1_PINH1.2, R2-PINH1.2, R5.2, R6.2, R7.2, R8.2, R9.2, R10.2, R_BOOT.2, R_CHANGE.2, R_CL1.2, R_RESET.2, U1.3 (!WP!(IO2)), U1.7 (!HOLD!/!RESET!(IO3)), U1.8 (VCC), U2.2 (3V3), U3.2 (VCC)
32KHZ: R2-PINH1.1, U2.9 (IO1), U3.1 (32KHZ)
DN: D1.4 (I/O2_2), J2.A7, J2.B7
DP: D1.6 (I/O1_2), J2.A6, J2.B6
EPD_3V3: C7.1, EPD_3V3.TP, EPD_C5.2, J1.15, J1.16, L1.2, Q2.2 (S)
EPD_3V3_C: EPD_3V3_C.TP, Q2.1 (G), R_CL1.1, U2.18 (IO20)
EPD_BUSY: EPD_BUSY.TP, J1.9, U2.26 (IO3)
EPD_CS: D6.2, EPD_CS.TP, J1.12, R9.1, U2.11 (IO10)
EPD_DC: EPD_DC.TP, J1.11, U2.5 (IO5)
EPD_RST: EPD_RST.TP, J1.10, U2.21 (IO23)
FLASH_CS: D9.2, R5.1, U1.1 (!CS), U2.12 (IO11)
GDR: J1.2, Q3.1 (G), R4.2
GND: BOOT_BUTTON.1, BOOT_BUTTON.2, C1.2, C1_BAT.2, C1_BAT1.2, C1_BAT2.2, C2.2, C2_BAT.2, C3.-, C4_USB.2, C5.2, C5_USB.2, C6.2, C7.2, C8.2, C9.2, C10.2, C10_SUPERCAP.1, CHANGE_BUTTON.1, CHANGE_BUTTON.2, C_DELAY.2, D1.2 (GND), D3.1 (K), D6.1, D8.1, D9.1, D10.1, D11.1, D12.1, EPD_C1.1, EPD_C2.1, EPD_C5.1, EPD_C6.1, EPD_C7\.1, EPD_C8.1, EPD_C9.1, EPD_C10.1, EPD_C11.1, EPD_C12.1, GND_1.TP, GND_2.TP, IC1.3 (GND), IC4.2 (VSS), J1.8, J1.17, J1.MP1, J1.MP2, J2.A1, J2.A12, J2.B1, J2.B12, J2.MP1, J2.MP2, J2.MP3, J2.MP4, J3.1, J4.G1 (GND_1), J4.G2 (GND_2), J4.G3 (GND_3), J4.G4 (GND_4), J4.P6 (VSS), MCP73831.2 (VSS), R1_PWRUSB.1, R2.1, R2-USB.2, R2-USB1.1, R2_BAT.1, R4.1, RESET_BUTTON.1, RESET_BUTTON.2, SENSOR2.1 (GND), SENSOR2.5 (SDO), SENSOR2.7 (GND), SJ1.1, U1.4 (GND), U1.9 (EXP), U2.1 (GND), U2.28 (GND), U2.29_1 (GND), U2.29_2 (GND), U2.29_3 (GND), U2.29_4 (GND), U2.29_5 (GND), U2.29_6 (GND), U2.29_7 (GND), U2.29_8 (GND), U2.29_9 (GND), U3.13 (GND), U4.1 (CTG), U4.4 (GND), U4.6 (QSTRT), U4.9 (EP)
GPIO8: R1.1, U2.10 (IO8)
I2C_PW: C1.1, C2.1, R1_PINH.2, R2-PINH.2, SENSOR2.2 (CSB), SENSOR2.6 (VDDIO), SENSOR2.8 (VDD), U2.17 (IO19)
INT_RTC: INT_RTC.TP, R1_PINH1.1, U2.8 (IO0), U3.3 (SQW/!INT)
IO/BOOT: BOOT_BUTTON.3, BOOT_BUTTON.4, C6.1, R_BOOT.1, U2.15 (IO9)
IO/CHANGE: C10.1, CHANGE_BUTTON.3, CHANGE_BUTTON.4, R_CHANGE.1, U2.23 (IO15)
MISO: D12.2, J4.P7 (DAT0), MISO.TP, R8.1, U1.2 (DO(IO1)), U2.27 (IO2)
MOSI: D11.2, J1.14, J4.P3 (CMD), MOSI.TP, R7.1, U1.5 (DI(IO0)), U2.7 (IO7)
unnamed: J2.A5, R2-USB1.2
unnamed: C1_BAT1.1, D2.1 (CATHODE), IC4.1 (VIN), IC4.3 (CE), Q1.2 (S)
unnamed: C4.1, D3.2 (A), D4.1 (K)
unnamed: MCP73831.1 (STAT), R1_BAT.2
unnamed: CHG_LED.C, R1_BAT.1
unnamed: C_DELAY.1, IC1.5 (CT)
unnamed: MCP73831.5 (PROG), R2_BAT.2
unnamed: J2.B5, R2-USB.1
unnamed: EPD_C1.2, J1.4
unnamed: EPD_C2.2, J1.5
unnamed: D7.1 (CATHODE), R_CAPACITOR.1
unnamed: EPD_C6.2, J1.18
unnamed: EPD_C7\.2, J1.19
unnamed: EPD_C8.2, J1.20
unnamed: EPD_C10.2, J1.22
unnamed: EPD_C12.2, J1.24
PREVGH: D5.1 (K), EPD_C9.2, J1.21
PREVGL: D4.2 (A), EPD_C11.2, J1.23
RESE: J1.3, Q3.2 (S), R3.2
RESE': R2.2, R3.1, SJ1.2
RESET: C5.1, IC1.1 (VOUT), RESET_BUTTON.3, RESET_BUTTON.4, R_RESET.1, U2.3 (EN)
RTC_RST: U2.16 (IO18), U3.4 (!RST)
RX: RX.TP, U2.24 (RXD0/GPIO17)
SCK: D10.2, J1.13, J4.P5 (CLK), R6.1, SCK.TP, U1.6 (CLK), U2.6 (IO6)
SCL: J3.4, R2-PINH.1, SENSOR2.4 (SCK), U2.20 (IO22), U3.16 (SCL), U4.7 (SCL)
SDA: J3.3, R1_PINH.1, SENSOR2.3 (SDI), U2.19 (IO21), U3.15 (SDA), U4.8 (SDA)
SRC: C4.2, D5.2 (A), L1.1, Q3.3 (D)
SS_SD: D8.2, J4.P2 (CD/DAT3), R10.1, U2.4 (IO4)
TX: TX.TP, U2.25 (TXD0/GPIO16)
USB_D+: D1.1 (I/O1_1), U2.14 (IO13)
USB_D-: D1.3 (I/O2_1), U2.13 (IO12)
VBAT: C2_BAT.1, MCP73831.3 (VBAT), Q1.3 (D), U4.2 (CELL), U4.3 (VDD), VBAT.TP
VBUS: C1_BAT.1, C4_USB.1, C5_USB.1, CHG_LED.A, D1.5 (VBUS), D2.2 (ANODE), MCP73831.4 (VIN), PFMF.050.1.2, Q1.1 (G), R1_PWRUSB.2, VBUS.TP
VRTC: C8.1, C10_SUPERCAP.2, R_CAPACITOR.2, U3.14 (VBAT)
VUSB: J2.A4, J2.A9, J2.B4, J2.B9, PFMF.050.1.1

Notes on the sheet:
EPD Power
E-Paper Display Header
E-Paper Drive Circuit
Display Type Selector
Li-Po Battery Charging Controller
ESP32 C6
SD Card
LDO Voltage Regulator
USB C connector & ESD protection
Environmental Sensor BME688
Battery Charge Level
Voltage Supervisor + Reset & Boot / IO Button
RTC Module DS3231SN
Test Pads
Qwiic / Stemma QT
SPI ESD Protection Lines
External NOR Flash 64MB
ebook_reader
Filip Dumitrașcu
DMG2305UX-7

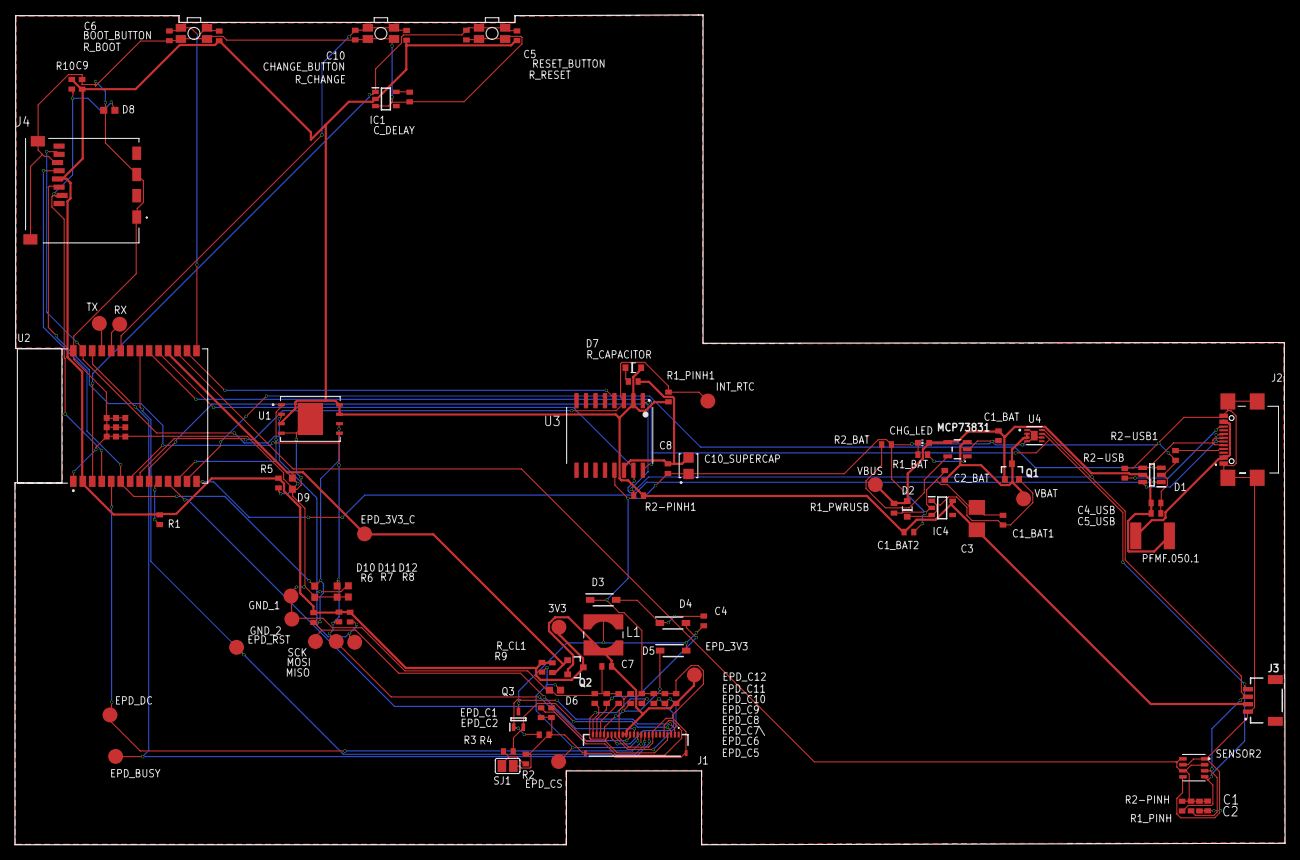
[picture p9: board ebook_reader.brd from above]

Board: 2 copper layers, 170.2 x 111.2 mm, 103 parts (0 on the bottom side), 55 nets.

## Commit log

2025-04-05 Final version
    [battery.step, display.step, ebook_reader.bom.csv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]
2025-04-05 File update
    [battery.step, display.step]
2025-04-11 Issues fixed
    [ebook_reader.brd, ebook_reader.sch]

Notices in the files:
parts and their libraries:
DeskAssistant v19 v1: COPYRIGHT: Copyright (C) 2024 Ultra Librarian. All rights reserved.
